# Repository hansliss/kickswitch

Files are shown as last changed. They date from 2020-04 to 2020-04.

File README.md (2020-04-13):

# kickswitch
Kickstart switcher for Amiga 2000

A switch for cramming 6 Kickstart images of different size into a single EPROM and make them switchable.

Switching is done by triggering a RESET low signal for at least two seconds, which can be done
from the keyboard by holding down CTRL-Amiga-Amiga.

Note that for some models of A500, you may need pullups on the address lines:
http://bax.comlab.uni-rostock.de/en/hardware/amiga500/kickstart-eprom/

A jumper is provided to select between pin 1 or 31 for A17 - older A2000 and A500 models
used the wrong pin for this.

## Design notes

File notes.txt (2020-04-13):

Main PCB

D1: https://www.elfa.se/en/small-signal-switching-diode-sod-123f-75-rnd-components-rnd-1n4148fl/p/30092888
C1, C2: https://www.elfa.se/en/capacitor-22-pf-0603-rnd-components-rnd-150mt18n220f100/p/30066212
C3: https://www.elfa.se/en/capacitor-uf-16-0603-kemet-c0603x104k4ractu/p/30111165
R1: https://www.elfa.se/en/smd-resistor-thick-film-10-kohm-0603-rnd-components-rnd-1550603saf1002t5e/p/30056457
U4: https://www.elfa.se/en/plug-adapter-dil-40-gold-plated-preci-dip-150-10-640-00-018101/p/14814851
Y1: https://www.elfa.se/en/quartz-hc49us-16-mhz-auris-16-00000m-hc49us-30-30-d32/p/17452832
U1: https://www.elfa.se/en/logic-ic-sot-23-sn74lvc1g08-texas-instruments-sn74lvc1g08dbvr/p/30023169
U2: https://www.elfa.se/en/logic-ic-sot-23-sn74lvc1g32-texas-instruments-sn74lvc1g32dbvr/p/30023189
U3: Atmega328P - Arduino Uno

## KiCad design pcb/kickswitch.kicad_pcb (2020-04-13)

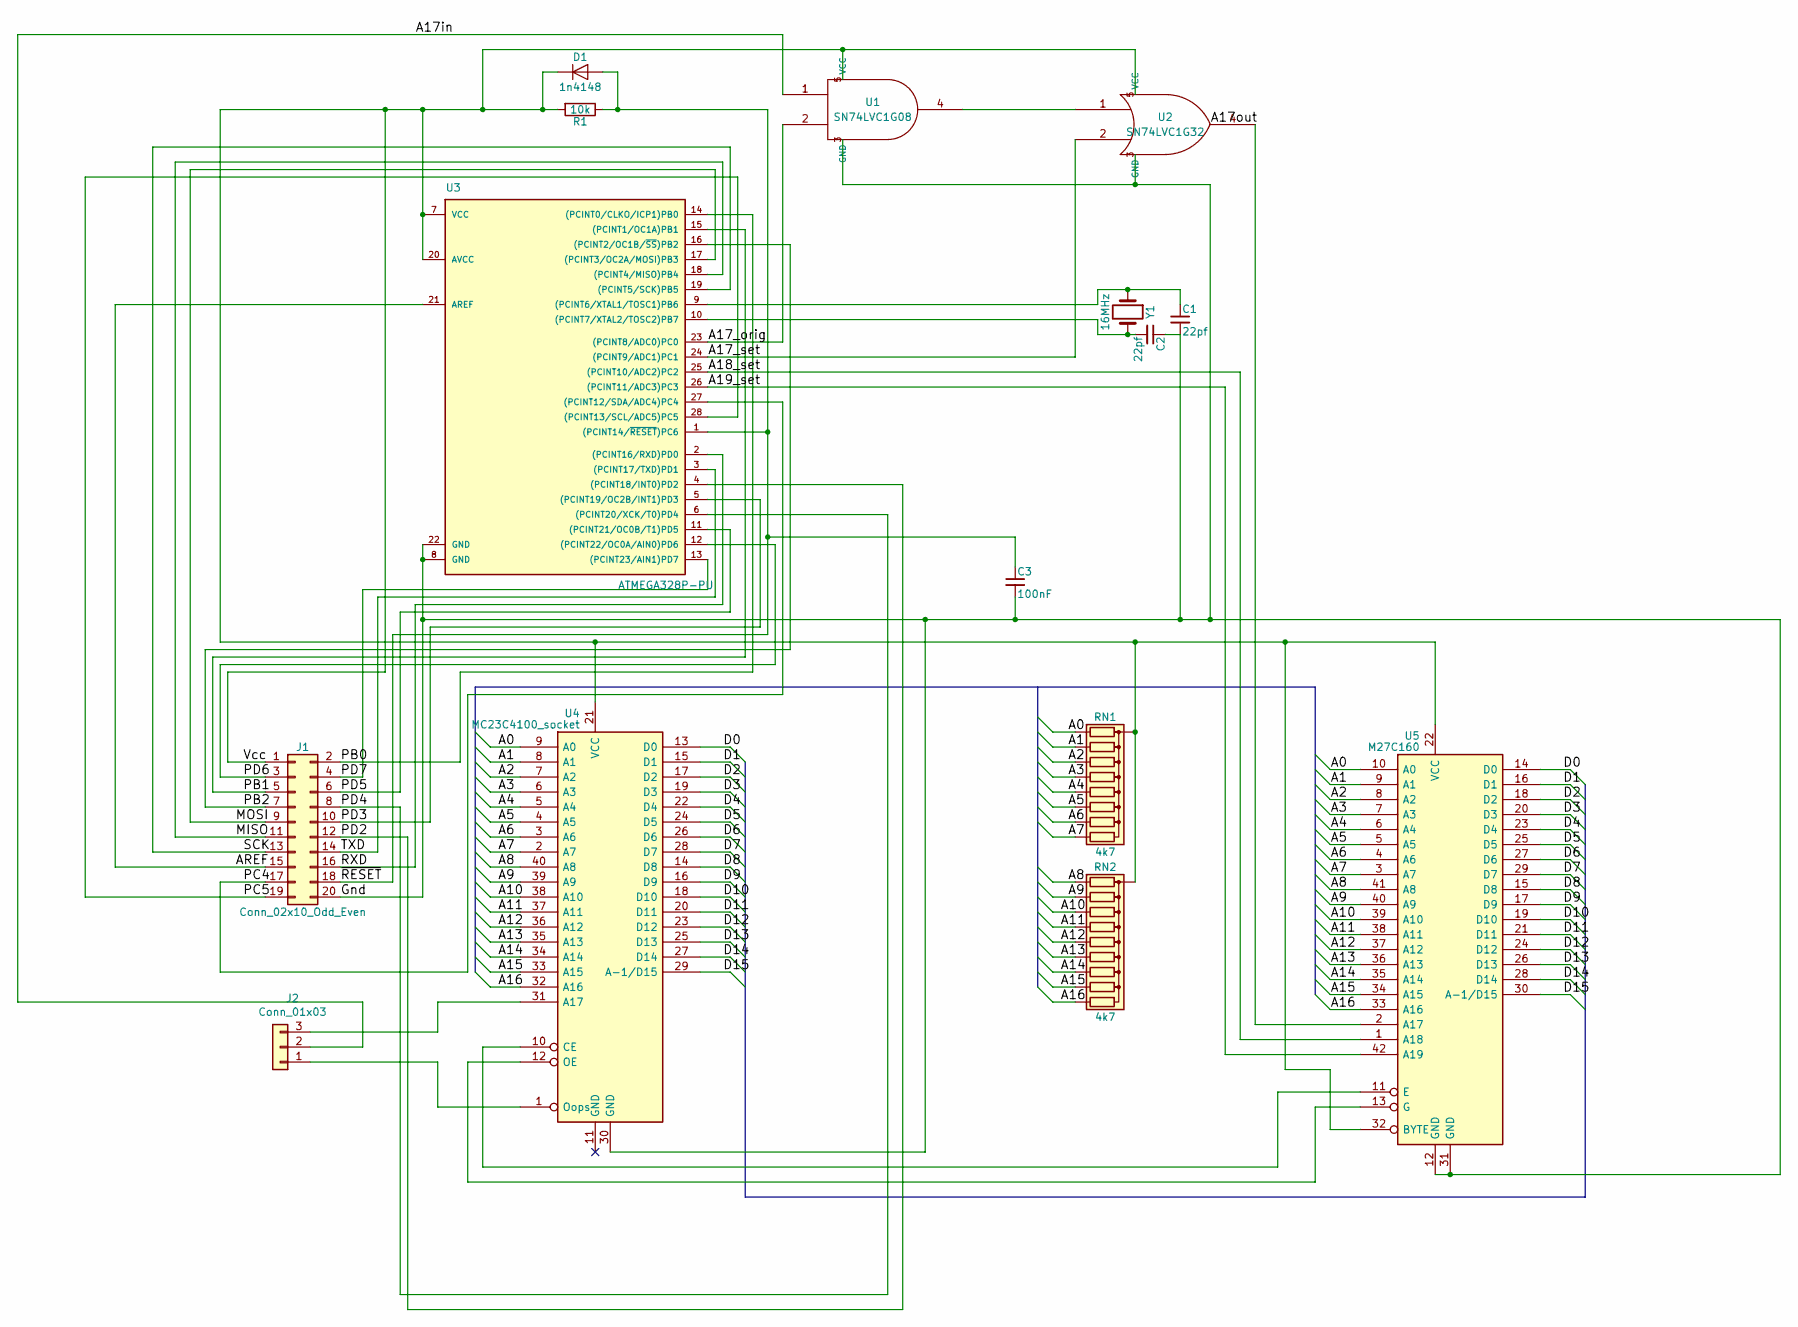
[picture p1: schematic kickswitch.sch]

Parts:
C1, C2: 22pf; C_0603
C3: 100nF; C_0603
D1: 1n4148; D_SOD-123F
J1: Conn_02x10_Odd_Even; Pin_Header_Straight_2x10_Pitch2.54mm
J2: Conn_01x03; Pin_Header_Straight_1x03_Pitch2.54mm
R1: 10k; R_0603
RN1: 4k7; R_Array_SIP9
RN2: 4k7; R_Array_SIP10
U1: SN74LVC1G08; SOT-23-5
U2: SN74LVC1G32; SOT-23-5
U3: ATMEGA328P-PU; DIP-28_W7.62mm
U4: MC23C4100_socket; DIP-40_W15.24mm_Socket
U5: M27C160; DIP-42_W15.24mm_Socket
Y1: 16MHz; Crystal_HC49-4H_Vertical

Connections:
/A0: RN1.2 (R1), U4.9 (A0), U5.10 (A0)
/A1: RN1.3 (R2), U4.8 (A1), U5.9 (A1)
/A2: RN1.4 (R3), U4.7 (A2), U5.8 (A2)
/A3: RN1.5 (R4), U4.6 (A3), U5.7 (A3)
/A4: RN1.6 (R5), U4.5 (A4), U5.6 (A4)
/A5: RN1.7 (R6), U4.4 (A5), U5.5 (A5)
/A6: RN1.8 (R7), U4.3 (A6), U5.4 (A6)
/A7: RN1.9 (R8), U4.2 (A7), U5.3 (A7)
/A8: RN2.2 (R1), U4.40 (A8), U5.41 (A8)
/A9: RN2.3 (R2), U4.39 (A9), U5.40 (A9)
/A10: RN2.4 (R3), U4.38 (A10), U5.39 (A10)
/A11: RN2.5 (R4), U4.37 (A11), U5.38 (A11)
/A12: RN2.6 (R5), U4.36 (A12), U5.37 (A12)
/A13: RN2.7 (R6), U4.35 (A13), U5.36 (A13)
/A14: RN2.8 (R7), U4.34 (A14), U5.35 (A14)
/A15: RN2.9 (R8), U4.33 (A15), U5.34 (A15)
/A16: RN2.10 (R9), U4.32 (A16), U5.33 (A16)
/A17_orig: U1.2, U3.23 ((PCINT8/ADC0)PC0)
/A17_set: U2.2, U3.24 ((PCINT9/ADC1)PC1)
/A17in: J2.2, U1.1
/A18_set: U3.25 ((PCINT10/ADC2)PC2), U5.1 (A18)
/A19_set: U3.26 ((PCINT11/ADC3)PC3), U5.42 (A19)
/AREF: J1.15, U3.21 (AREF)
/D0: U4.13 (D0), U5.14 (D0)
/D1: U4.15 (D1), U5.16 (D1)
/D2: U4.17 (D2), U5.18 (D2)
/D3: U4.19 (D3), U5.20 (D3)
/D4: U4.22 (D4), U5.23 (D4)
/D5: U4.24 (D5), U5.25 (D5)
/D6: U4.26 (D6), U5.27 (D6)
/D7: U4.28 (D7), U5.29 (D7)
/D8: U4.14 (D8), U5.15 (D8)
/D9: U4.16 (D9), U5.17 (D9)
/D10: U4.18 (D10), U5.19 (D10)
/D11: U4.20 (D11), U5.21 (D11)
/D12: U4.23 (D12), U5.24 (D12)
/D13: U4.25 (D13), U5.26 (D13)
/D14: U4.27 (D14), U5.28 (D14)
/D15: U4.29 (A-1/D15), U5.30 (A-1/D15)
/Gnd: C1.2, C2.1, C3.2, J1.20, U1.3 (GND), U2.3 (GND), U3.8 (GND), U3.22 (GND), U4.30 (GND), U5.12 (GND), U5.31 (GND)
/MISO: J1.11, U3.18 ((PCINT4/MISO)PB4)
/MOSI: J1.9, U3.17 ((PCINT3/OC2A/MOSI)PB3)
/PB0: J1.2, U3.14 ((PCINT0/CLKO/ICP1)PB0)
/PB1: J1.5, U3.15 ((PCINT1/OC1A)PB1)
/PB2: J1.7, U3.16 ((PCINT2/OC1B/~SS~)PB2)
/PC4: J1.17, U3.27 ((PCINT12/SDA/ADC4)PC4)
/PC5: J1.19, U3.28 ((PCINT13/SCL/ADC5)PC5)
/PD2: J1.12, U3.4 ((PCINT18/INT0)PD2)
/PD3: J1.10, U3.5 ((PCINT19/OC2B/INT1)PD3)
/PD4: J1.8, U3.6 ((PCINT20/XCK/T0)PD4)
/PD5: J1.6, U3.11 ((PCINT21/OC0B/T1)PD5)
/PD6: J1.3, U3.12 ((PCINT22/OC0A/AIN0)PD6)
/PD7: J1.4, U3.13 ((PCINT23/AIN1)PD7)
/RXD: J1.16, U3.2 ((PCINT16/RXD)PD0)
/SCK: J1.13, U3.19 ((PCINT5/SCK)PB5)
/TXD: J1.14, U3.3 ((PCINT17/TXD)PD1)
/Vcc: D1.1 (K), J1.1, R1.2, RN1.1 (common), RN2.1 (common), U1.5 (VCC), U2.5 (VCC), U3.7 (VCC), U3.20 (AVCC), U4.21 (VCC), U5.22 (VCC), U5.32 (BYTE)
/~RESET: C3.1, D1.2 (A), J1.18, R1.1, U3.1 ((PCINT14/~RESET~)PC6)
unnamed: C1.1, U3.9 ((PCINT6/XTAL1/TOSC1)PB6), Y1.1
unnamed: C2.2, U3.10 ((PCINT7/XTAL2/TOSC2)PB7), Y1.2
unnamed: J2.1, U4.1 (Oops)
unnamed: J2.3, U4.31 (A17)
unnamed: U1.4, U2.1
unnamed: U2.4, U5.2 (A17)
unnamed: U4.10 (CE), U5.11 (E)
unnamed: U4.12 (OE), U5.13 (G)

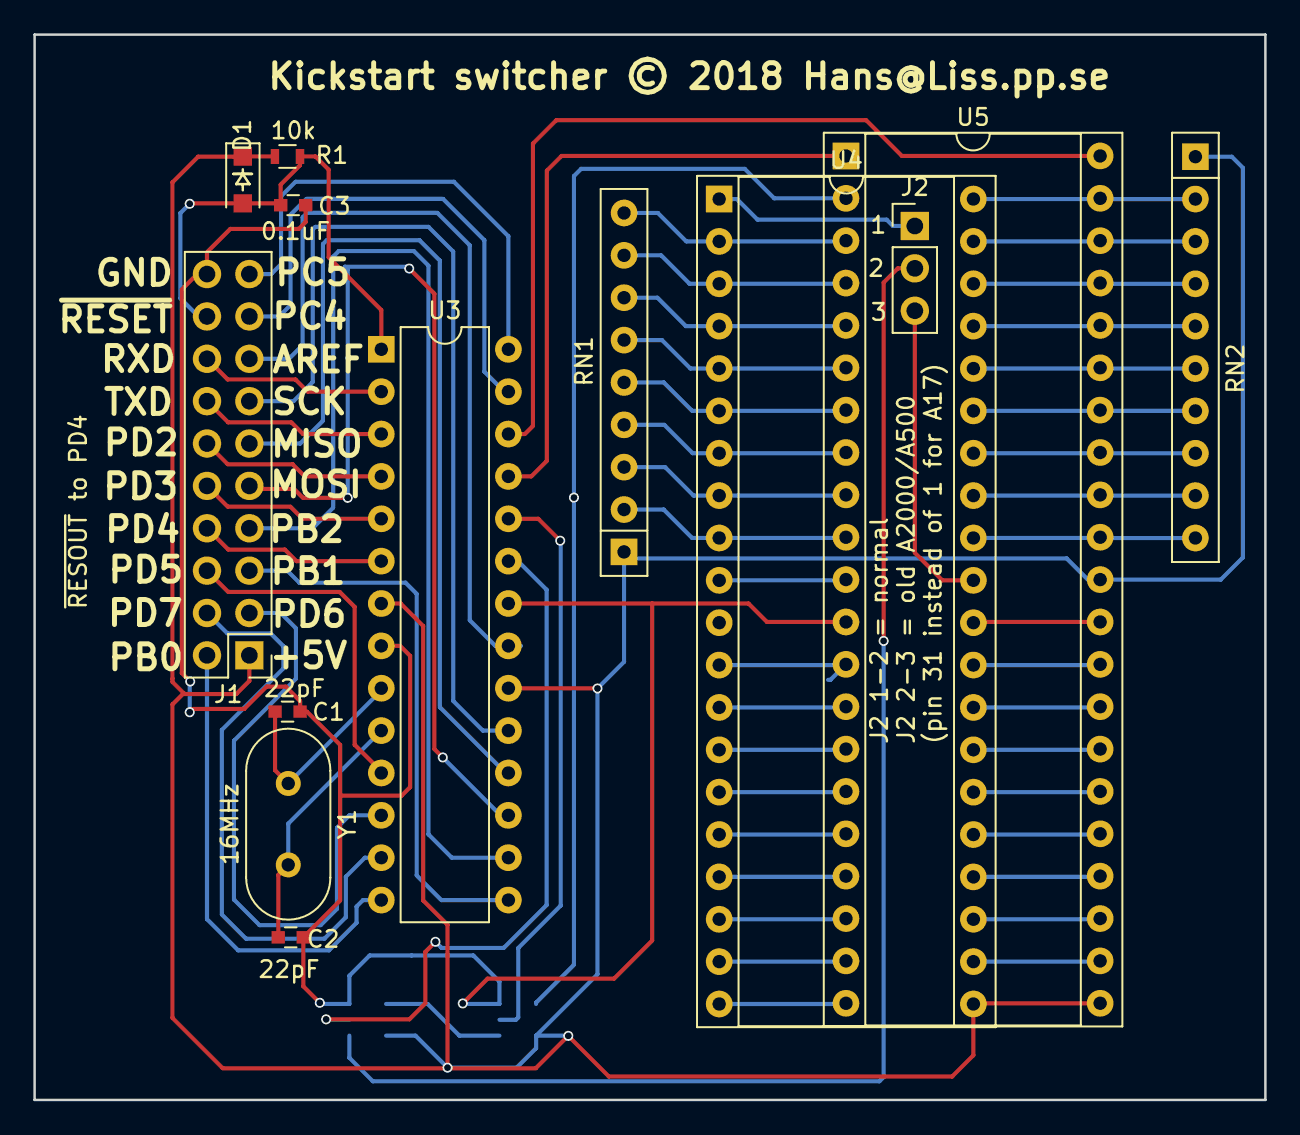
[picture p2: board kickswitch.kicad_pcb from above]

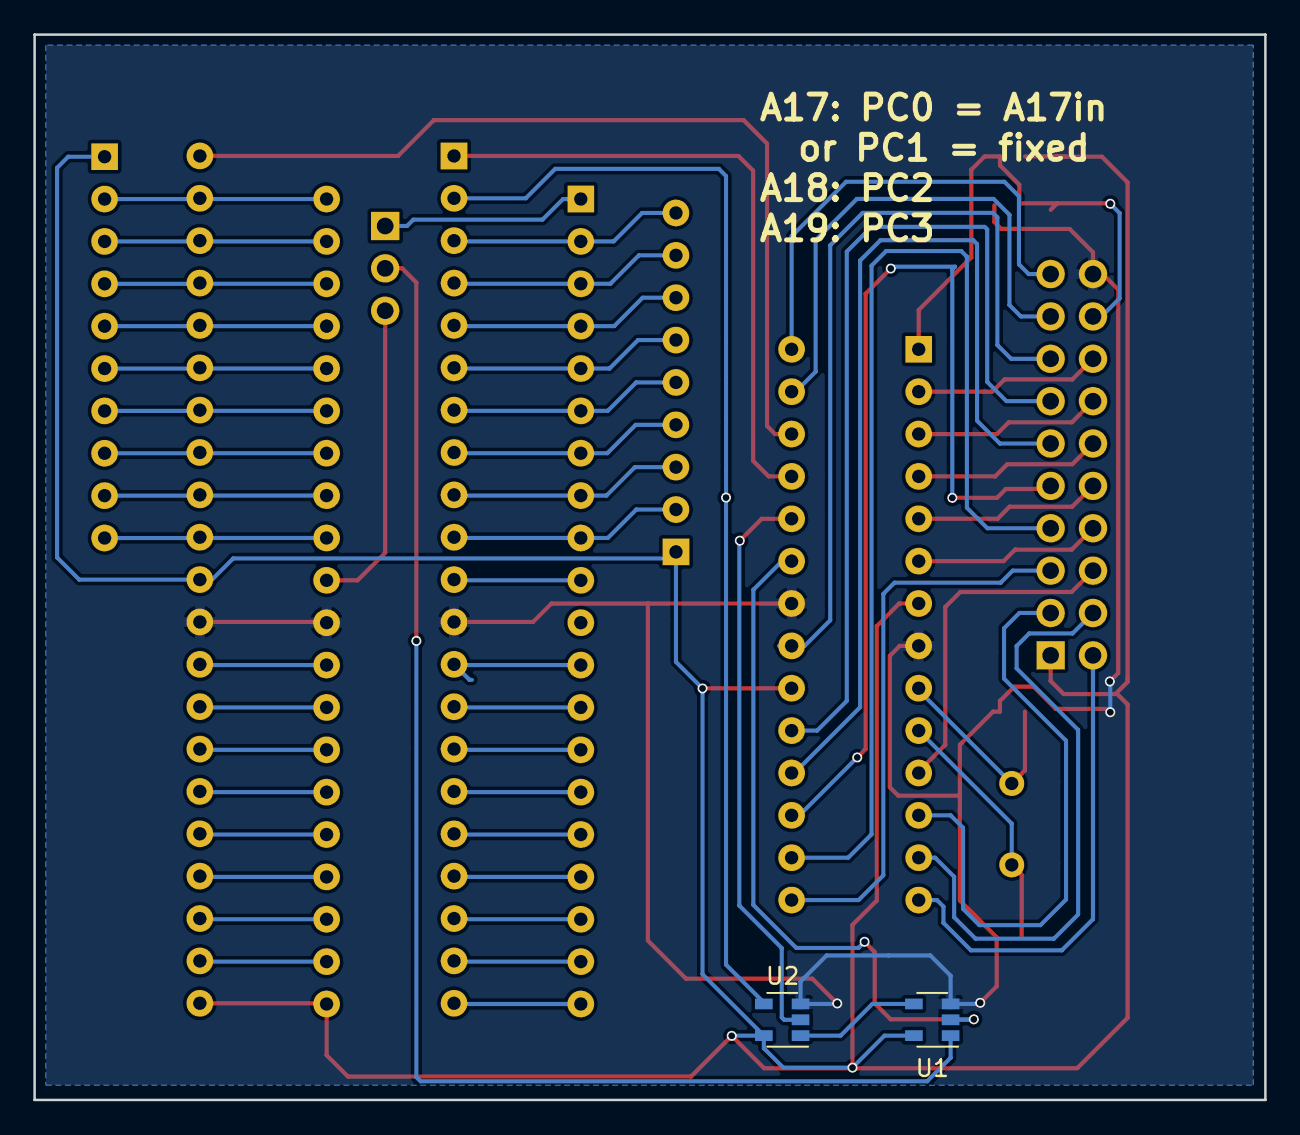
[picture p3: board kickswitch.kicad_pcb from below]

Board: 2 copper layers, 73.8 x 63.9 mm, 15 parts (2 on the bottom side), 66 nets.

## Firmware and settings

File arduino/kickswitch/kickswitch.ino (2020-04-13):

/*
 * Kickswitch code
 * Produce adressing signals to a banked Kickstart ROM for A17 to A19 on PC0, PC1, PC2 and PC3 based on a selected value.
 * The value can be changed by holding a signal low for at least two seconds. This is intended to be taken from the
 * /RSTOUT signal on the parallel port on the Amiga, which will make it possible to switch between different Kickstart
 * versions by holding down CTRL-Amiga-Amiga for two seconds.
 * With six Kickstart images in a single ROM, the first four 128kW, and the last two 256kW, we need to be able to either
 * ignore the original A17 (for the first four) or use it (for the last two). The circuit will allow us to use PC0 to pass
 * through the original A17 to the ROM, or leave that off and use PC1 to set it HIGH/LOW. A18 and A19 are controlled by
 * PC2 and PC3, respectively. So we use a simple switch statement and set the appropriate values whenever the switch changes.
 */

#include <EEPROM.h>

#define RSTPin 4

int pc0 = 14;
int pc1 = 15;
int pc2 = 16;
int pc3 = 17;

int pinsByVal[] = {0x00, 0x02, 0x04, 0x06, 0x09, 0x0D};

int v;
int oldv;
int RSTState=HIGH;

void setup() {
  pinMode(pc0, OUTPUT);
  pinMode(pc1, OUTPUT);
  pinMode(pc2, OUTPUT);
  pinMode(pc3, OUTPUT);
  pinMode(RSTPin, INPUT_PULLUP);
  oldv = -1;
  v = EEPROM.read(0);
#ifdef SERIAL
  Serial.begin(9600);
#endif
}

long ResetMillis=-1;

void loop() {
  int curRSTState = digitalRead(RSTPin);
  if (curRSTState != RSTState) {
    if (curRSTState == LOW) {
      ResetMillis = millis();
    }
    RSTState = curRSTState;
  }
  if (RSTState == LOW && ResetMillis != -1) {
    long elapsed = millis() - ResetMillis;
    if (elapsed >= 2000) {
      v = (v + 1) % 6;
      ResetMillis = -1;
    }
  }
  if (v != oldv && RSTState == LOW) {
#ifdef SERIAL
    Serial.println(String(v) + ": " + String(pinsByVal[v]));
#endif
    oldv = v;
    EEPROM.write(0, v);
    digitalWrite(pc0, (pinsByVal[v] & 0x01)?HIGH:LOW);
    digitalWrite(pc1, (pinsByVal[v] & 0x02)?HIGH:LOW);
    digitalWrite(pc2, (pinsByVal[v] & 0x04)?HIGH:LOW);
    digitalWrite(pc3, (pinsByVal[v] & 0x08)?HIGH:LOW);
  }
  delay(200);
}

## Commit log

2018-06-22 Initial import
    [kickswitch.kicad_pcb, kickswitch.sch]
2018-06-22 Added NET file and component library
    [kickswitch.sch]
2018-06-22 Latest version. Added Arduino code
    [kickswitch.kicad_pcb, kickswitch.sch]
2018-06-22 Added Gerber files
    [kickswitch-B.Cu.gbr, kickswitch-B.Mask.gbr, kickswitch-B.SilkS.gbr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]
2018-07-05 Added many more I/O pins Removed reset button Added resistor nets for Address line pullups Added ground plane
    [kickswitch-B.Cu.gbr, kickswitch-B.Mask.gbr, kickswitch-B.SilkS.gbr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]
2018-07-05 Added TODO note in Arduino code
    [kickswitch-drl_map.gbr]
2018-07-05 Added 8-to-3 encoder pcb
    [encoder-B.Cu.gbr, encoder-B.Mask.gbr, encoder-B.SilkS.gbr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]
2018-07-05 Added power flags to encoder
    [encoder.sch]
2018-07-19 Added component list for encoder
2018-07-29 Fixed bugs in new Arduino code after testing
    [kickswitch.ino]
2020-04-13 Upgraded to latest KiCAD. Eliminated encoder. Eliminated switch and added /RSTOUT input line instead. Added jumper for pin 1/31 "Oops" fix. Updated README.md.
    [encoder-B.Cu.gbr, encoder-B.Mask.gbr, encoder-B.SilkS.gbr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]

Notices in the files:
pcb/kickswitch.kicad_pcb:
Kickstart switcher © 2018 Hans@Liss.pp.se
